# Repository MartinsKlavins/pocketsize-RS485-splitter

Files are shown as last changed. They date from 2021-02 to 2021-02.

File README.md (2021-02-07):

# Pocketsize RS485 splitter
Pocketsize RS485 splitter for DMX512 signal. Created for everyday use with focus on problematic device isolation, connection for far separated devices, simple "Y" type splitting.

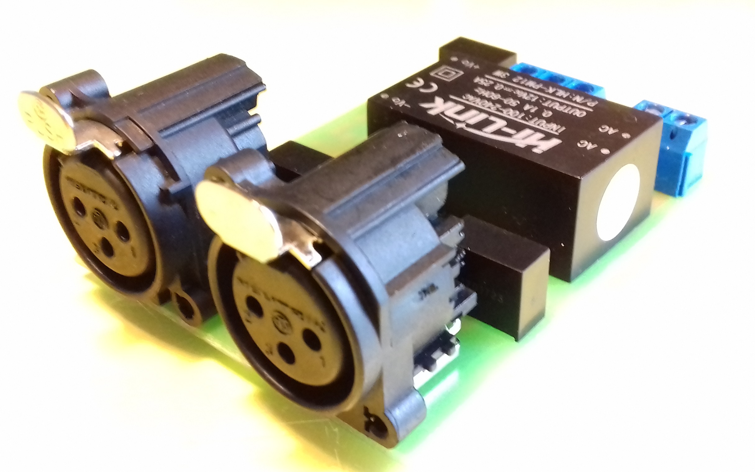
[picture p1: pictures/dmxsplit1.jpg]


### Technical info
* It is active, have seperate power supply for each DMX output and input.
* Galvanic and optic isolation for each DMX output and input.
* MAX485, 6N137 and 74HC14 for signal pathway.

### Notes
* AC/DC and DC/DC converters are main advantage of this splitter. Power supply is created with 4 converters. First stage – 230V AC to 12V DC, second stage – multiple 12/05V DC/DC. There are variety of them, but I don’t suggest to use 05/05 (because they didn’t gave steady 5V output, atleast not for me). Didn’t helped capacitors and LDO (for example L4941BV) for stabilization. Any way, the are small-sized and great solution!

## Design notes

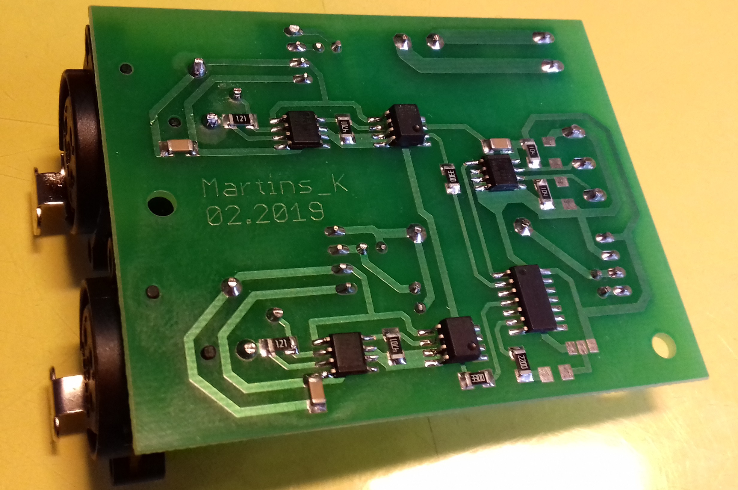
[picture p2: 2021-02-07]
pictures/dmxsplit4.jpg

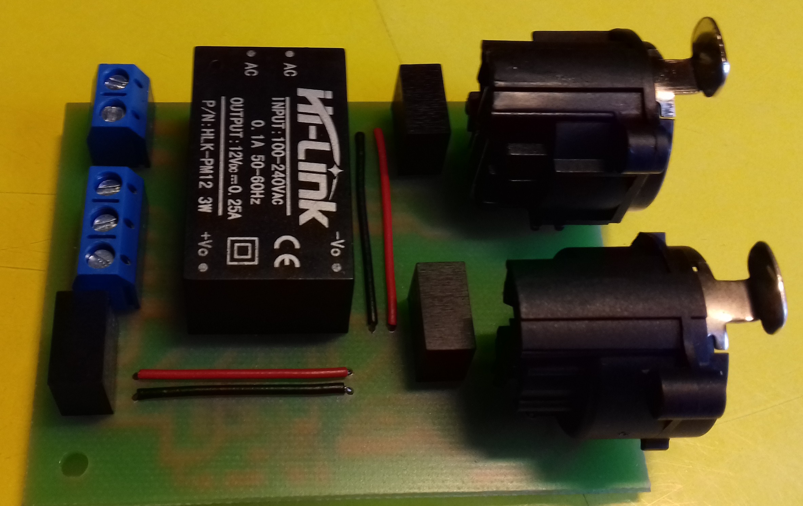
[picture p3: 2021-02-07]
pictures/dmxsplit2.jpg

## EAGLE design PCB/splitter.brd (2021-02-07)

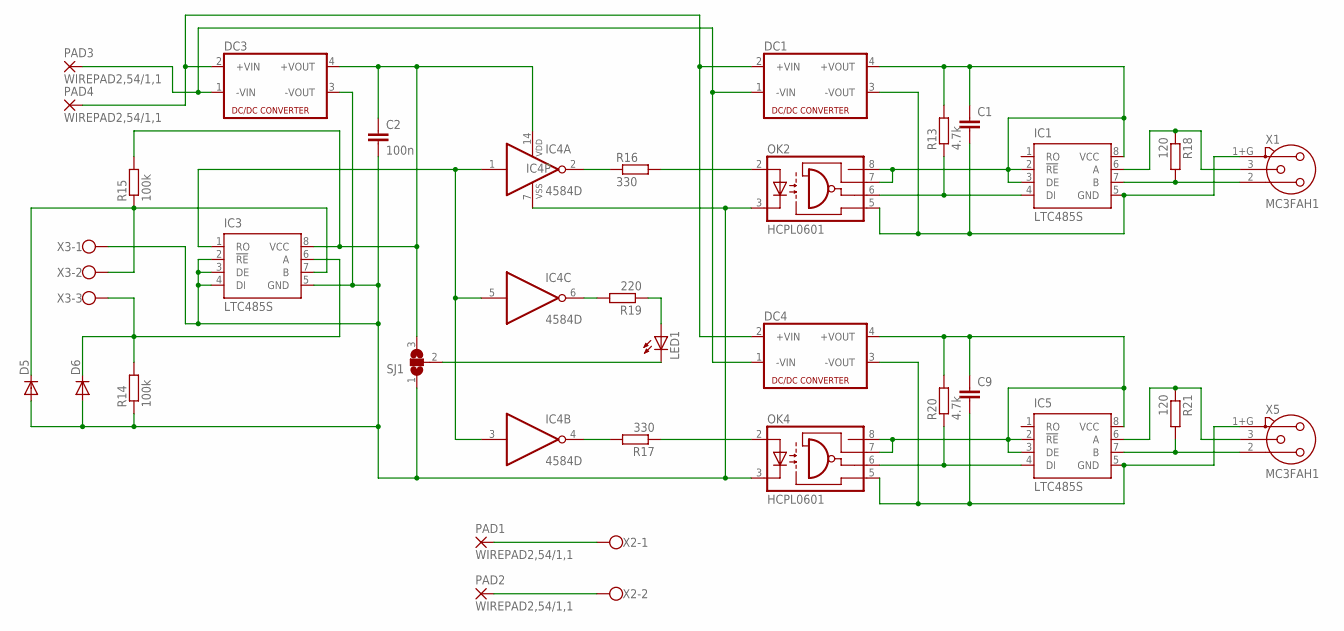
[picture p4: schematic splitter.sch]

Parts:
C1, C9: C-EUC1206K; C1206K
C2: 100n; C1206K
D5, D6: DIODE-SOD80C; SOD80C
DC1, DC3, DC4: NME
IC1, IC3, IC5: LTC485S; SOIC8
IC4: 4584D; SO14
LED1: LED_E; LED_1206
OK2, OK4: HCPL0601; SOIC08
PAD1, PAD2, PAD3, PAD4: WIREPAD2,54/1,1; 2,54/1,1
R13, R20: 4.7k; M1206
R14, R15: 100k; M1206
R16, R17: 330; M1206
R18, R21: 120; M1206
R19: 220; M1206
SJ1: SJ2W; SJ_2
X1, X5: MC3FAH1; NC3FAH1
X2: W237-102
X3: W237-103

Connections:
unnamed: LED1.C, SJ1.2
unnamed: IC1.6 (A), R18.1, X1.3
unnamed: IC5.7 (B), R21.2, X5.2
unnamed: IC1.4 (DI), OK2.6 (VO), R13.1
unnamed: C1.1, DC1.4 (+VOUT), IC1.2 (!RE), IC1.3 (DE), IC1.8 (VCC), OK2.7 (VE), OK2.8 (VCC), R13.2
unnamed: IC5.6 (A), R21.1, X5.3
unnamed: IC5.4 (DI), OK4.6 (VO), R20.1
unnamed: C9.2, DC4.3 (-VOUT), IC5.5 (GND), OK4.5 (GND), X5.1+G (1)
unnamed: C9.1, DC4.4 (+VOUT), IC5.2 (!RE), IC5.3 (DE), IC5.8 (VCC), OK4.7 (VE), OK4.8 (VCC), R20.2
unnamed: IC4.2 (O), R16.1
unnamed: OK2.2 (A), R16.2
unnamed: IC4.4 (O), R17.2
unnamed: OK4.2 (A), R17.1
unnamed: IC3.1 (RO), IC4.1 (I), IC4.3 (I), IC4.5 (I)
unnamed: D6.C, IC3.6 (A), R14.2, X3.3
unnamed: IC1.7 (B), R18.2, X1.2
unnamed: C2.1, DC3.4 (+VOUT), IC3.8 (VCC), IC4.14 (VDD), R15.2, SJ1.3
unnamed: C2.2, D5.A, D6.A, DC3.3 (-VOUT), IC3.2 (!RE), IC3.3 (DE), IC3.4 (DI), IC3.5 (GND), IC4.7 (VSS), OK2.3 (C), OK4.3 (C), R14.1, SJ1.1, X3.1
unnamed: D5.C, IC3.7 (B), R15.1, X3.2
unnamed: IC4.6 (O), R19.2
unnamed: DC1.1 (-VIN), DC3.1 (-VIN), DC4.1 (-VIN), PAD3.1
unnamed: DC1.2 (+VIN), DC3.2 (+VIN), DC4.2 (+VIN), PAD4.1
unnamed: PAD2.1, X2.2
unnamed: PAD1.1, X2.1
unnamed: LED1.A, R19.1
unnamed: C1.2, DC1.3 (-VOUT), IC1.5 (GND), OK2.5 (GND), X1.1+G (1)

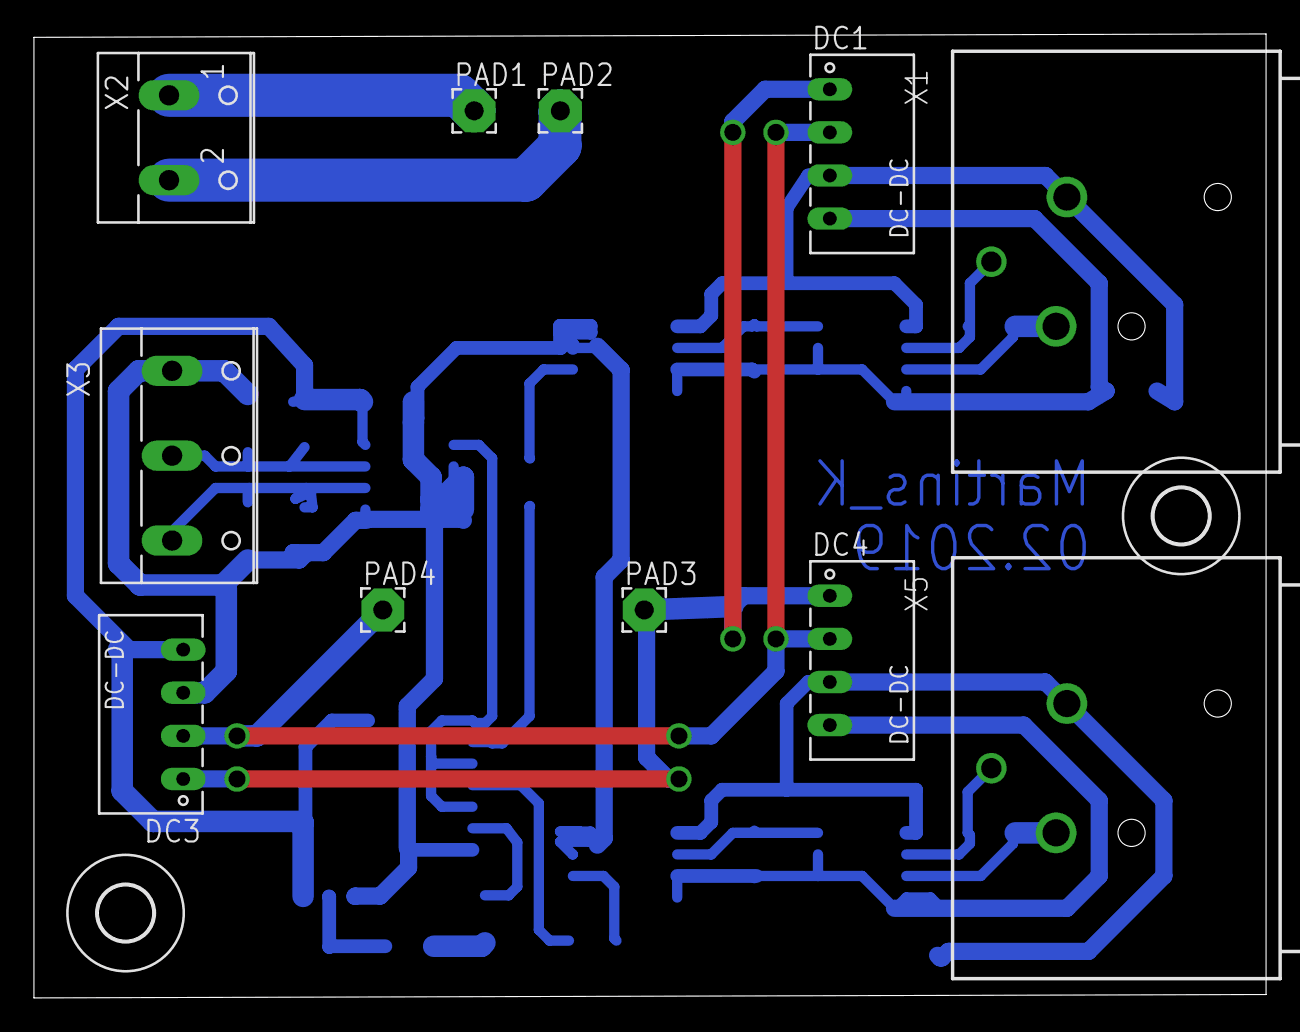
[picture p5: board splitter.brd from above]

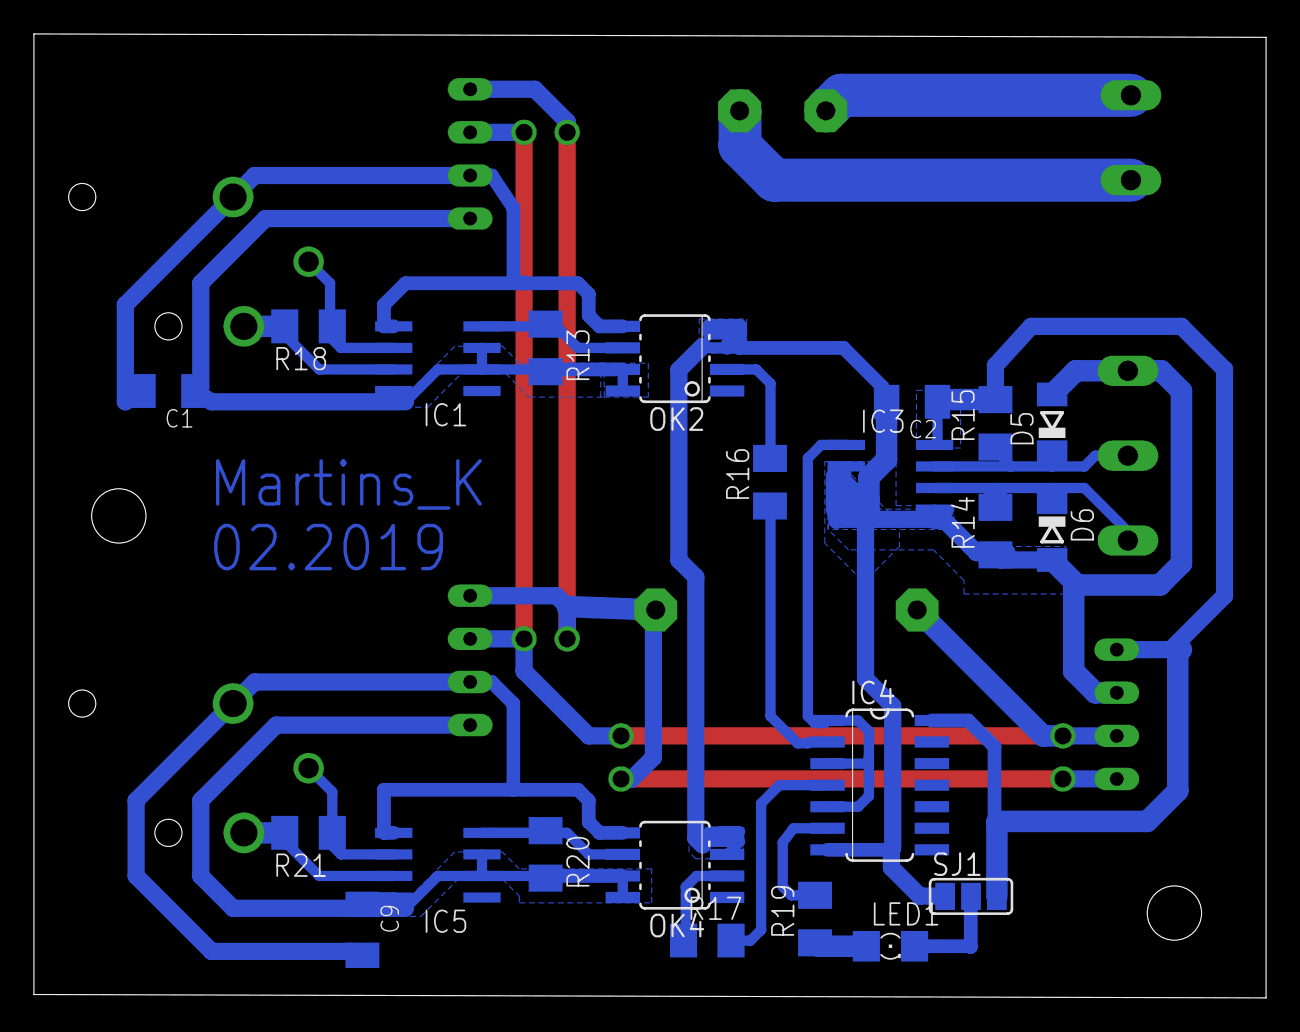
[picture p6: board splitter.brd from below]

Board: 2 copper layers, 72.6 x 56.8 mm, 35 parts (22 on the bottom side), 26 nets.

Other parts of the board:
U$1, U$2: 3,2
